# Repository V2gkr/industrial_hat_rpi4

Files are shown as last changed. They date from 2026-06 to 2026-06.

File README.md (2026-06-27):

HAT for Raspberry PI 4 with isolated rs232 , rs485 , CAN-FD

This board was made for personal use with other projects.
outputs for manufacturing:
1) gerbers and drill files
2) BOM for jlcpcb store
3) pick and place file

Board capabilities
1) isolated RS232 on standart UART pins (8 , 10)
2) isolated RS485 on additional UART with enable pin (27,28,29)
3) isolated CAN-FD on SPI0 (standard pins with interrupt pin on pin 15)

Production cost on jlcpcb for 5 prototypes is app. 150$

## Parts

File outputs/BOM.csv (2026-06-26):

Reference | Value | Footprint | LCSC
C1,C2,C3,C4,C5,C6,C7 | 100n | Capacitor_SMD:C_0402_1005Metric | C60474
C8,C9 | 1u | Capacitor_SMD:C_0603_1608Metric | C3905328
C10,C11 | 20p | Capacitor_SMD:C_0402_1005Metric | C76959
D1,D4 | PESD1CAN,215 | Package_TO_SOT_SMD:SOT-23 | C15771
D2,D3 | LED | LED_SMD:LED_0603_1608Metric | C99289
D5 | PESD5V0X1BT,215 | Package_TO_SOT_SMD:SOT-23-3 | C456094
J1 | KH-2.54FH-1X20P-H8.5 | Connector_PinSocket_2.54mm:PinSocket_2x20_P2.54mm_Vertical | C2905423
J2 | 2.54-1*2PFemale | Connector_PinSocket_2.54mm:PinSocket_1x02_P2.54mm_Vertical | C49661
J3,J4 | WJ2EDGRC-5.08-03P-14-00A | Connector_Phoenix_GMSTB:PhoenixContact_GMSTBA_2,5_3-G-7,62_1x03_P7.62mm_Horizontal | C8377
R1,R2 | 120 | Resistor_SMD:R_0603_1608Metric | C114681
R3,R14,R15 | 10k | Resistor_SMD:R_0603_1608Metric | C22369937
R4,R5,R6,R7,R8,R9,R10,R11,R12,R13,R18,R19,R20,R21 | 100 | Resistor_SMD:R_0603_1608Metric | C163844
R16,R17 | 220 | Resistor_SMD:R_0603_1608Metric | C384263
R22,R23 | 680 | Resistor_SMD:R_0603_1608Metric | C25253
SW1,SW2 | DSIC01TSGER | Button_Switch_SMD:SW_DIP_SPSTx01_Slide_Copal_CHS-01B_W7.62mm_P1.27mm | C5145031
U1 | MCP2518FD-xQBB | Package_DFN_QFN:DFN-14-1EP_3x4.5mm_P0.65mm_EP1.65x4.25mm | C621395
U2,U4 | ISO6742 | Package_SO:SOIC-16W_7.5x10.3mm_P1.27mm | C5216407
U3 | TCAN3413 | Package_SO:SOIC-8_3.9x4.9mm_P1.27mm | C22433320
U6 | SP3485EN | Package_SO:SOIC-8_3.9x4.9mm_P1.27mm | C22386564
U7 | B0303S-1W | Converter_DCDC:Converter_DCDC_Murata_CRE1xxxxxxSC_THT | C20622556
Y1 | X322520MSB4SI | Crystal:Crystal_SMD_3225-4Pin_3.2x2.5mm | C9004

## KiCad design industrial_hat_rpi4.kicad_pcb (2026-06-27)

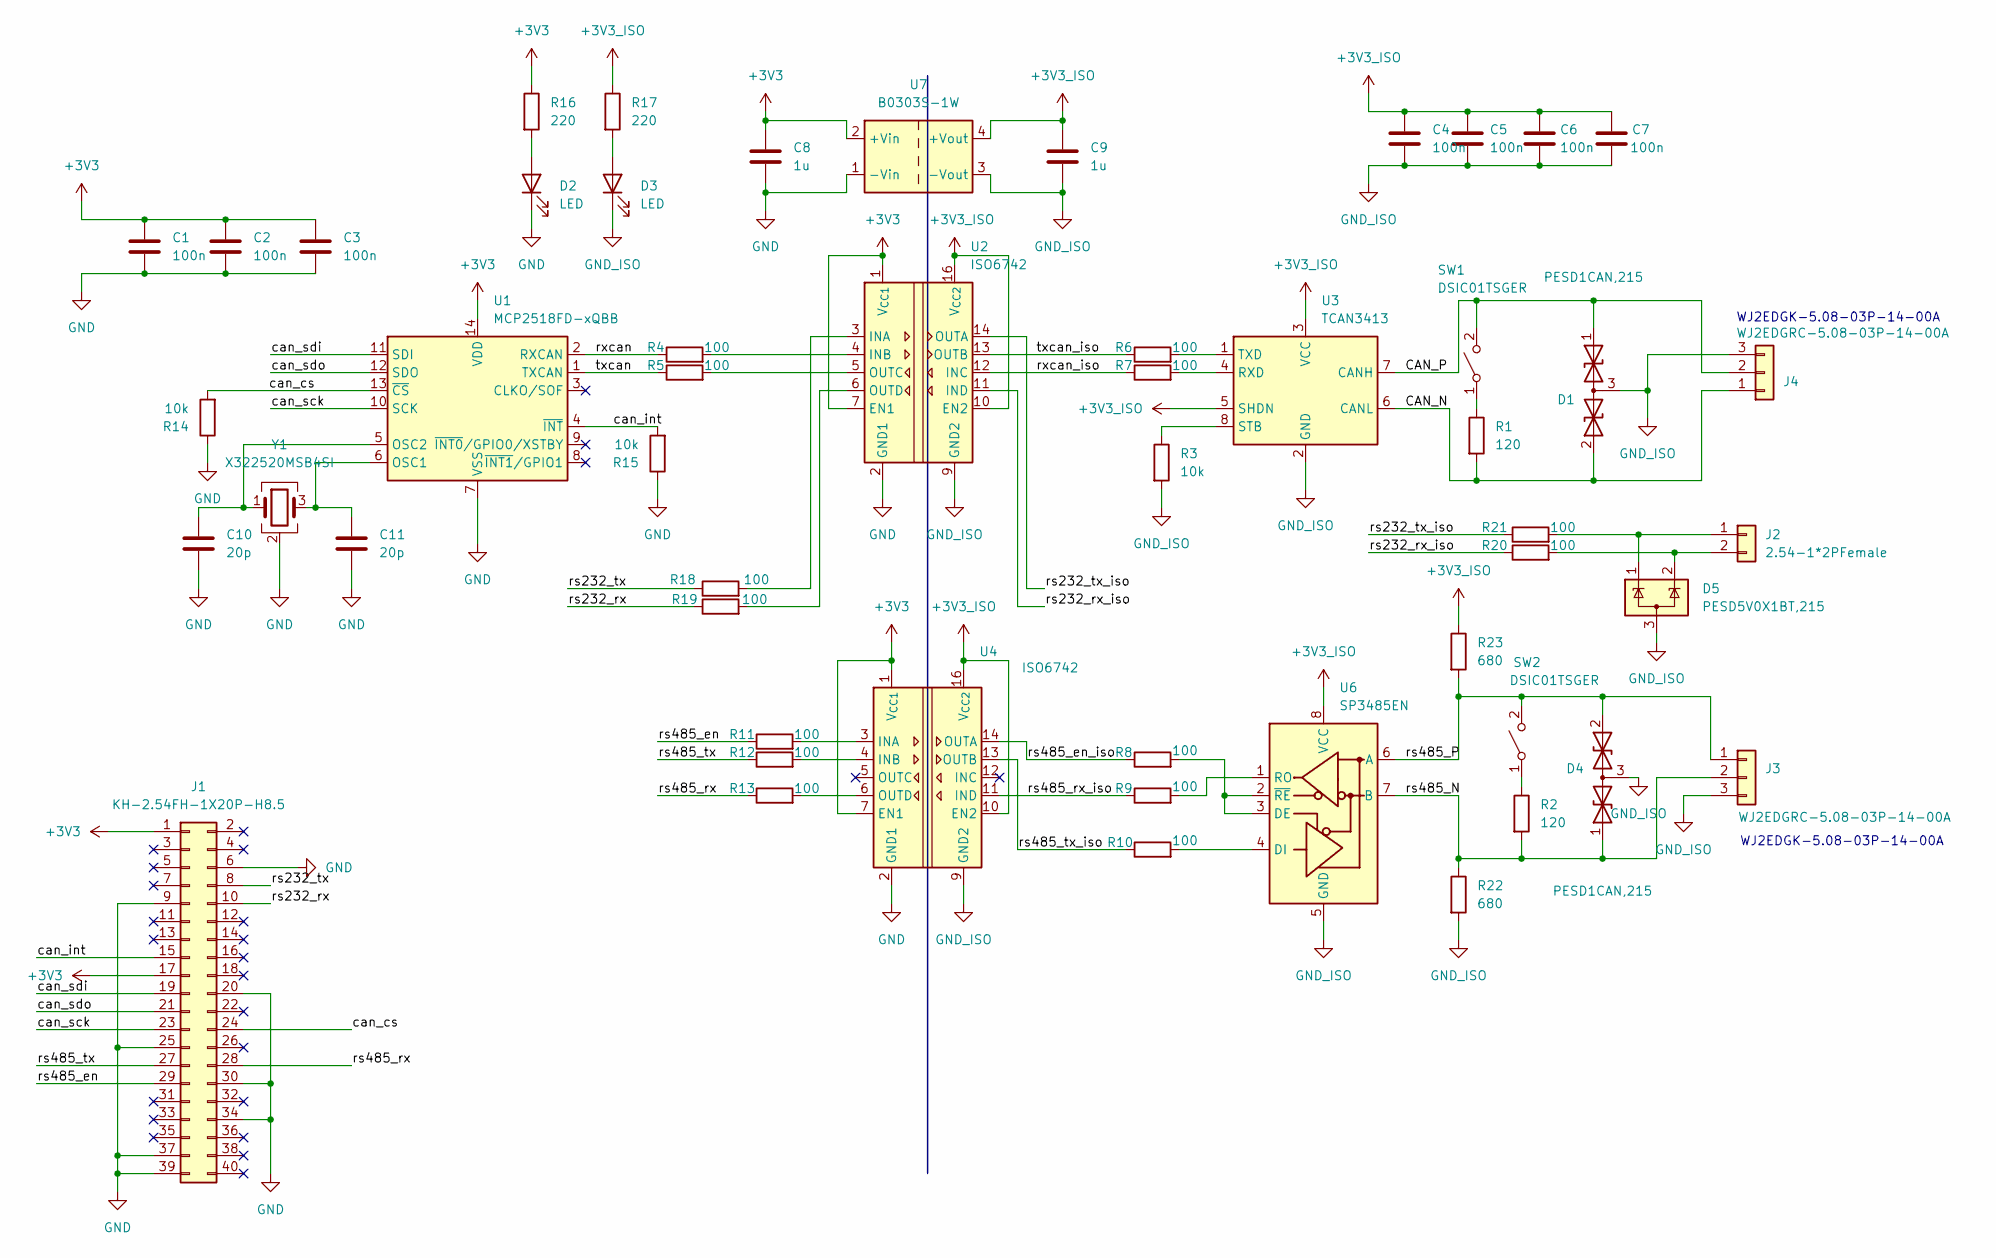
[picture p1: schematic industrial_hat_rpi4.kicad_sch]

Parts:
C1, C2, C3, C4, C5, C6, C7: 100n; C_0402_1005Metric; LCSC C60474
C8, C9: 1u; C_0603_1608Metric; LCSC C3905328
C10, C11: 20p; C_0402_1005Metric; LCSC C76959
D1, D4: PESD1CAN,215; SOT-23; LCSC C15771
D2, D3: LED; LED_0603_1608Metric; LCSC C99289
D5: PESD5V0X1BT,215; SOT-23-3; LCSC C456094
J1: KH-2.54FH-1X20P-H8.5; PinSocket_2x20_P2.54mm_Vertical_jlcbpcb_pnp_custom; LCSC C2905423
J2: 2.54-1*2PFemale; PinSocket_1x02_P2.54mm_Vertical_jlcpcb_pnp_custom; LCSC C49661
J3, J4: WJ2EDGRC-5.08-03P-14-00A; PhoenixContact_MSTBA_2,5_3-G-5,08_1x03_P5.08mm_Horizontal; LCSC C8377
R1, R2: 120; R_0603_1608Metric; LCSC C114681
R3, R14, R15: 10k; R_0603_1608Metric; LCSC C22369937
R4, R5, R6, R7, R8, R9, R10, R11, R12, R13, R18, R19, R20, R21: 100; R_0603_1608Metric; LCSC C163844
R16, R17: 220; R_0603_1608Metric; LCSC C384263
R22, R23: 680; R_0603_1608Metric; LCSC C25253
SW1, SW2: DSIC01TSGER; SW_DIP_SPSTx01_Slide_Copal_CHS-01B_W7.62mm_P1.27mm; LCSC C5145031
U1: MCP2518FD-xQBB; DFN-14-1EP_3x4.5mm_P0.65mm_EP1.65x4.25mm; LCSC C621395
U2, U4: ISO6742; SOIC-16W_7.5x10.3mm_P1.27mm; LCSC C5216407
U3: TCAN3413; SOIC-8_3.9x4.9mm_P1.27mm; LCSC C22433320
U6: SP3485EN; SOIC-8_3.9x4.9mm_P1.27mm; LCSC C22386564
U7: B0303S-1W; Converter_DCDC_Murata_CRE1xxxxxxSC_THT_jlcpcb_pnp_custom; LCSC C20622556
Y1: X322520MSB4SI; Crystal_SMD_3225-4Pin_3.2x2.5mm; LCSC C9004

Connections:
+3V3: C1.1, C2.1, C3.1, C8.1, J1.1, J1.17, R16.1, U1.14 (VDD), U2.1 (V_{CC1}), U2.7 (EN1), U4.1 (V_{CC1}), U4.7 (EN1), U7.2 (+Vin)
+3V3_ISO: C4.1, C5.1, C6.1, C7.1, C9.1, R17.1, R23.1, U2.10 (EN2), U2.16 (V_{CC2}), U3.3 (VCC), U3.5 (SHDN), U4.10 (EN2), U4.16 (V_{CC2}), U6.8 (VCC), U7.4 (+Vout)
/CAN_N: D1.2 (A2), J4.1, R1.2, U3.6 (CANL)
/CAN_P: D1.1 (A1), J4.2, SW1.2 (B), U3.7 (CANH)
/can_cs: J1.24, R14.2, U1.13 (~CS)
/can_int: J1.15, R15.2, U1.4 (~INT)
/can_sck: J1.23, U1.10 (SCK)
/can_sdi: J1.19, U1.11 (SDI)
/can_sdo: J1.21, U1.12 (SDO)
/rs232_rx: J1.10, R19.1
/rs232_rx_iso: R20.1, U2.11 (IND)
/rs232_tx: J1.8, R18.1
/rs232_tx_iso: R21.1, U2.14 (OUTA)
/rs485_N: D4.1 (A1), J3.2, R2.2, R22.1, U6.7 (B)
/rs485_P: D4.2 (A2), J3.1, R23.2, SW2.2 (B), U6.6 (A)
/rs485_en: J1.29, R11.1
/rs485_en_iso: R8.1, U4.14 (OUTA)
/rs485_rx: J1.28, R13.1
/rs485_rx_iso: R9.1, U4.11 (IND)
/rs485_tx: J1.27, R12.1
/rs485_tx_iso: R10.1, U4.13 (OUTB)
/rxcan: R4.1, U1.2 (RXCAN)
/rxcan_iso: R7.1, U2.12 (INC)
/txcan: R5.1, U1.1 (TXCAN)
/txcan_iso: R6.1, U2.13 (OUTB)
GND: C1.2, C2.2, C3.2, C8.2, C10.2, C11.2, D2.1 (K), J1.6, J1.9, J1.20, J1.25, J1.30, J1.34, J1.37, J1.39, R14.1, R15.1, U1.7 (VSS), U1.15 (VSS), U2.2 (GND1), U2.8 (GND1), U4.2 (GND1), U4.8 (GND1), U7.1 (-Vin), Y1.2 (G), Y1.4 (G)
GND_ISO: C4.2, C5.2, C6.2, C7.2, C9.2, D1.3 (common), D3.1 (K), D4.3 (common), D5.3 (A), J3.3, J4.3, R3.2, R22.2, U2.9 (GND2), U2.15 (GND2), U3.2 (GND), U4.9 (GND2), U4.15 (GND2), U6.5 (GND), U7.3 (-Vout)
unnamed: D2.2 (A), R16.2
unnamed: D3.2 (A), R17.2
unnamed: D5.1 (K), J2.1, R21.2
unnamed: D5.2 (K), J2.2, R20.2
unnamed: R1.1, SW1.1 (A)
unnamed: R2.1, SW2.1 (A)
unnamed: C11.1, U1.6 (OSC1), Y1.3
unnamed: C10.1, U1.5 (OSC2), Y1.1
unnamed: R18.2, U2.3 (INA)
unnamed: R4.2, U2.4 (INB)
unnamed: R5.2, U2.5 (OUTC)
unnamed: R19.2, U2.6 (OUTD)
unnamed: R7.2, U3.4 (RXD)
unnamed: R3.1, U3.8 (STB)
unnamed: R6.2, U3.1 (TXD)
unnamed: R11.2, U4.3 (INA)
unnamed: R12.2, U4.4 (INB)
unnamed: R13.2, U4.6 (OUTD)
unnamed: R8.2, U6.2 (~RE), U6.3 (DE)
unnamed: R10.2, U6.4 (DI)
unnamed: R9.2, U6.1 (RO)

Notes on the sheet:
WJ2EDGK-5.08-03P-14-00A

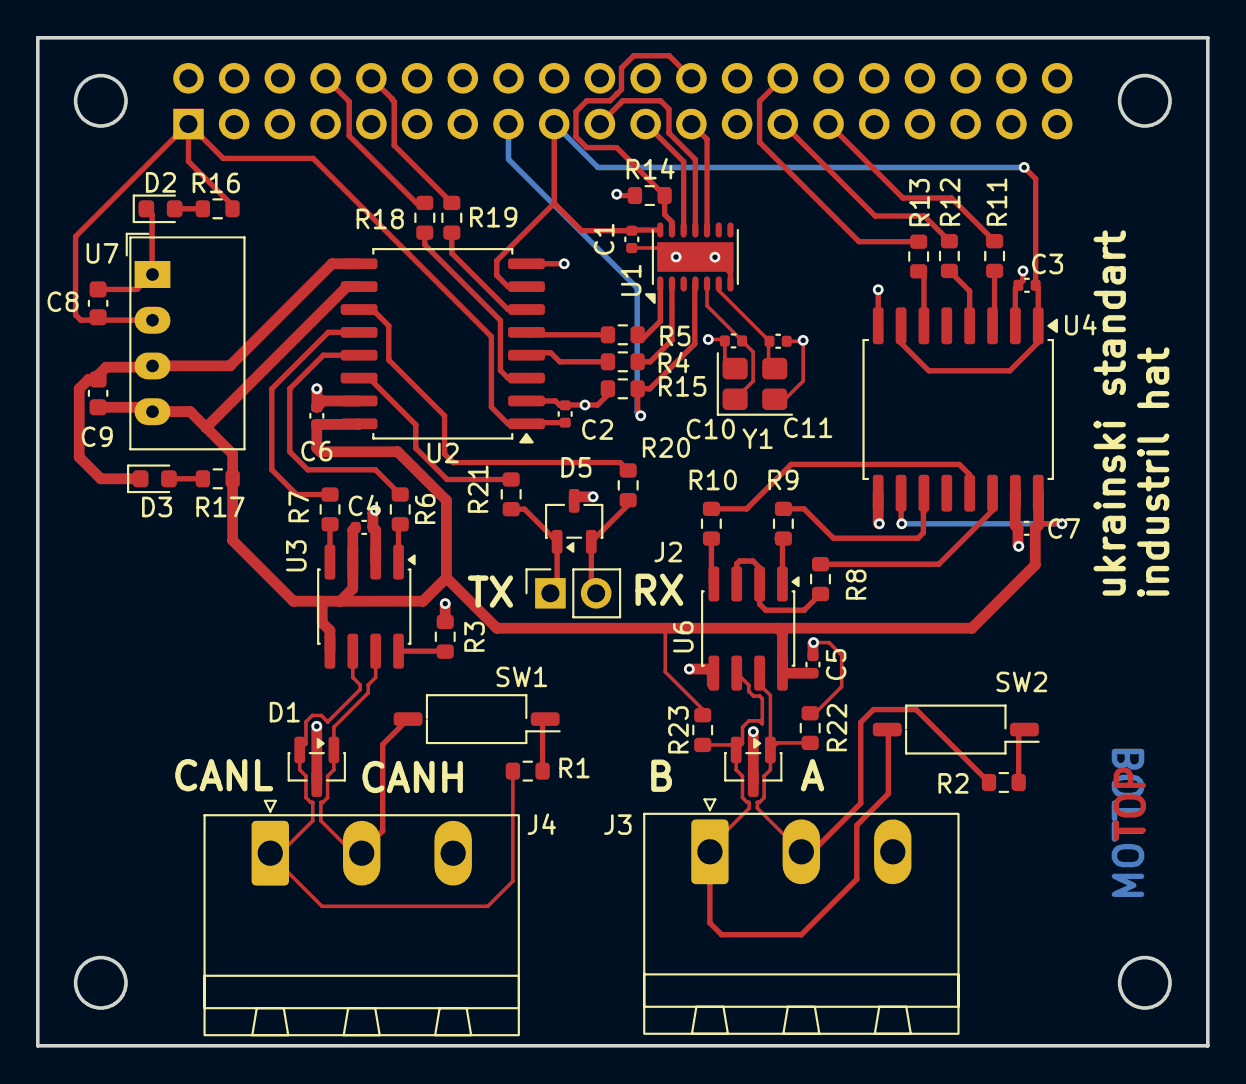
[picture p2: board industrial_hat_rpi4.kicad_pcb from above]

Board: 2 copper layers, 65.0 x 56.0 mm, 52 parts (1 on the bottom side), 48 nets.

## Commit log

2026-06-22 added decoupling caps
    [industrial_hat_rpi4.kicad_sch]
2026-06-22 added differential line components
    [industrial_hat_rpi4.kicad_sch]
2026-06-23 changed isolators , assigned partnumbers
    [industrial_hat_rpi4.kicad_sch]
2026-06-23 schematic cleanup
    [industrial_hat_rpi4.kicad_sch]
2026-06-23 changed termination resistor switches
    [industrial_hat_rpi4.kicad_sch]
2026-06-23 added pcb
    [industrial_hat_rpi4.kicad_pcb, industrial_hat_rpi4.kicad_sch]
2026-06-23 assigned jlcpcb parts , pcb component placing inp
    [industrial_hat_rpi4.kicad_pcb, industrial_hat_rpi4.kicad_sch]
2026-06-23 component placement inp
    [industrial_hat_rpi4.kicad_pcb]
2026-06-24 changed component placing and can , rs485 connectors
    [industrial_hat_rpi4.kicad_sch]
2026-06-25 changed can ,rs485 connections , routing in progress
    [industrial_hat_rpi4.kicad_pcb, industrial_hat_rpi4.kicad_sch]
2026-06-26 completed pcb
    [industrial_hat_rpi4.kicad_pcb, industrial_hat_rpi4.kicad_sch]
2026-06-26 added rs485 pull up down resistors, generated bom
    [industrial_hat_rpi4.csv, industrial_hat_rpi4.kicad_pcb, industrial_hat_rpi4.kicad_sch]
2026-06-26 removed history directory
    [industrial_hat_rpi4.kicad_pcb]
2026-06-26 changed silkscreen text placement
    [industrial_hat_rpi4.kicad_pcb]
2026-06-26 updated switches footprints and layout
    [industrial_hat_rpi4.kicad_pcb, industrial_hat_rpi4.kicad_sch]
2026-06-26 added pick and place and bom in outputs folder
    [BOM.csv, industrial_hat_rpi4.csv]
2026-06-26 added gerber and drill files
2026-06-26 added pick and place in csv
    [industrial_hat_rpi4.kicad_pcb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]
2026-06-26 updated output files
    [BOM.csv, industrial_hat_rpi4.kicad_pcb, industrial_hat_rpi4.kicad_sch]
2026-06-27 final output files , small changes to footprints
    [industrial_hat_rpi4.kicad_pcb, industrial_hat_rpi4.kicad_sch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]
